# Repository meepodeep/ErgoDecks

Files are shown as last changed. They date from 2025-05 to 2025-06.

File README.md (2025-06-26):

# ErgoDecks not ErgoDOX
- ## Featuring
  - ### Two independent Bluetooth halves.
  - ### 3d printed case
  - ### Custom PCB
  - ### Kalih Choc switch compatibility.

**BOM**

| Item |Quantity |Total price+Shipping|Use in project|Item source|
| --- | --- | --- | --- | --- |
| Pcb  | 5x (minimum order) |$32.05|Mount Everything to this| JLCPCB |
| NRF52840	  | 2x |$10.77|Drive the boards|[Aliexpress](https://www.aliexpress.us/item/3256807018711621.html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)|
|Kalih Choc 10pc	|4x|$31.00|Be switches|[Little Keyboards](https://www.littlekeyboards.com/collections/keyboard-switches/products/kailh-choc-low-profile-switches)|
|Filament of your choice|an amount|0$|make the case|wherever you buy filament ( I have this)|
|301230 lithium battery|2x|$8.76|Power The boards|[Aliexpress](https://www.aliexpress.us/item/3256806602655947.html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)|
|1N4148 Diodes 100pc|1x|$9.26|be diodes|[Aliexpress](https://www.aliexpress.us/item/3256806058794623.html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)|
|Keycaps 1u 10pc|x4|$21.11|be keycaps|[adafruit](https://www.adafruit.com/product/5737)|
|Keycaps 1.5u 2pc|x2|$4.66|be keycaps|[Aliexpress](https://www.aliexpress.us/item/3256805730011012.html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)|
|Everything||$105.62|||

## **Download Gerbers.zip for the gerbers and ErgoDecksVx.3mf/.step/.f3z for the case!**
- ## **Assembly**
  - Solder diodes onto the PCB.
  - Solder switches onto the PCB.
  - Solder microcontrollers onto the pcb.
  - Solder the battery to the bat terminals on the mcu.
  - Attach the battery using double sided tape to the bottom half of the case in the battery area.
  - 
  - Use m3 bolts to secure the pcb and top case to the bottom half of the case.

- ## **Software**
  - download the firmware.zip file and flash the left file to the left half and the right file to the right half by dragging and dropping it into the virtual disk on the MCUs in bootloader mode.






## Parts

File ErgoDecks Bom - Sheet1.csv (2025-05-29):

Item | Quantity | Total price+Shipping | Use In project | Item Source
Pcb | 5x minimum | $32.05 | Mount everything | JLCPCB
NRF52840 | 2x | $10.77 | Drive the boards | https://www.aliexpress.us/item/3256807018711621.html?
Kalih Choc 10pc | 4x | $31.00 | Be switches | https://www.littlekeyboards.com/collections/keyboard-switches/products/kailh-choc-low-profile-switches
301230 lithium battery | 2x | $8.76 | Power the boards | https://www.aliexpress.us/item/3256806602655947
Filament | 1x | $0 | Case | Already owned
1N4148 Diodes 50pc | 1x | $1.28 | be diodes | https://www.aliexpress.us/item/3256806058794623.html
Keycaps 10pc 1u | 3x | $17.10 | Be keycaps | https://www.adafruit.com/product/5737
Keycaps 2pc 1.5u | 2x | $4.66 | be keycaps | https://www.aliexpress.us/item/3256805730011012.htm
Everything |  | $105.62

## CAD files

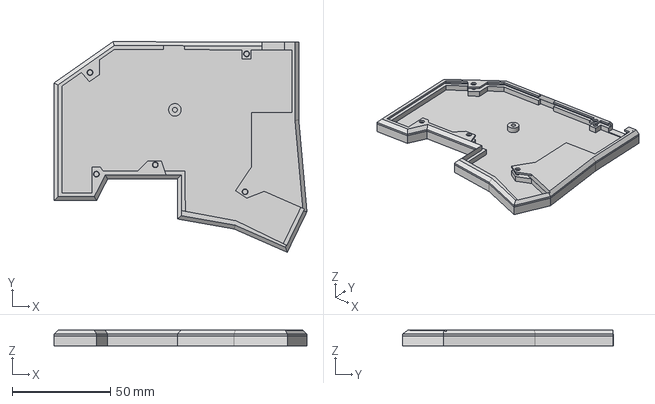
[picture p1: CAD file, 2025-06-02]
ErgoDecks v7.step
128.9 x 107.4 x 8.00 mm

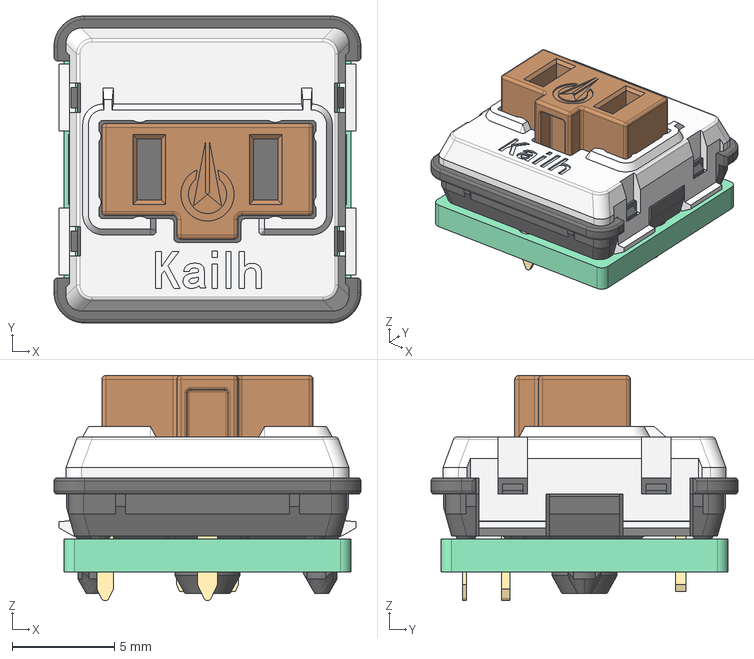
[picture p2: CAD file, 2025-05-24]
ErgoDecks/Kailh Choc Low Profile Switch.step
15.0 x 15.0 x 11.0 mm

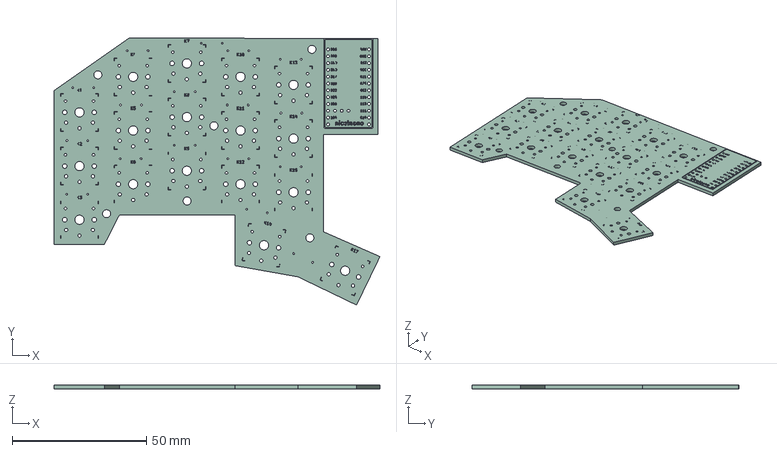
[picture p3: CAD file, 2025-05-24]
ErgoDecks/ErgoDecks.step
121.5 x 99.5 x 1.66 mm
ErgoDecks_silkscreen
ErgoDecks_PCB

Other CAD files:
ErgoDecks v6.f3z

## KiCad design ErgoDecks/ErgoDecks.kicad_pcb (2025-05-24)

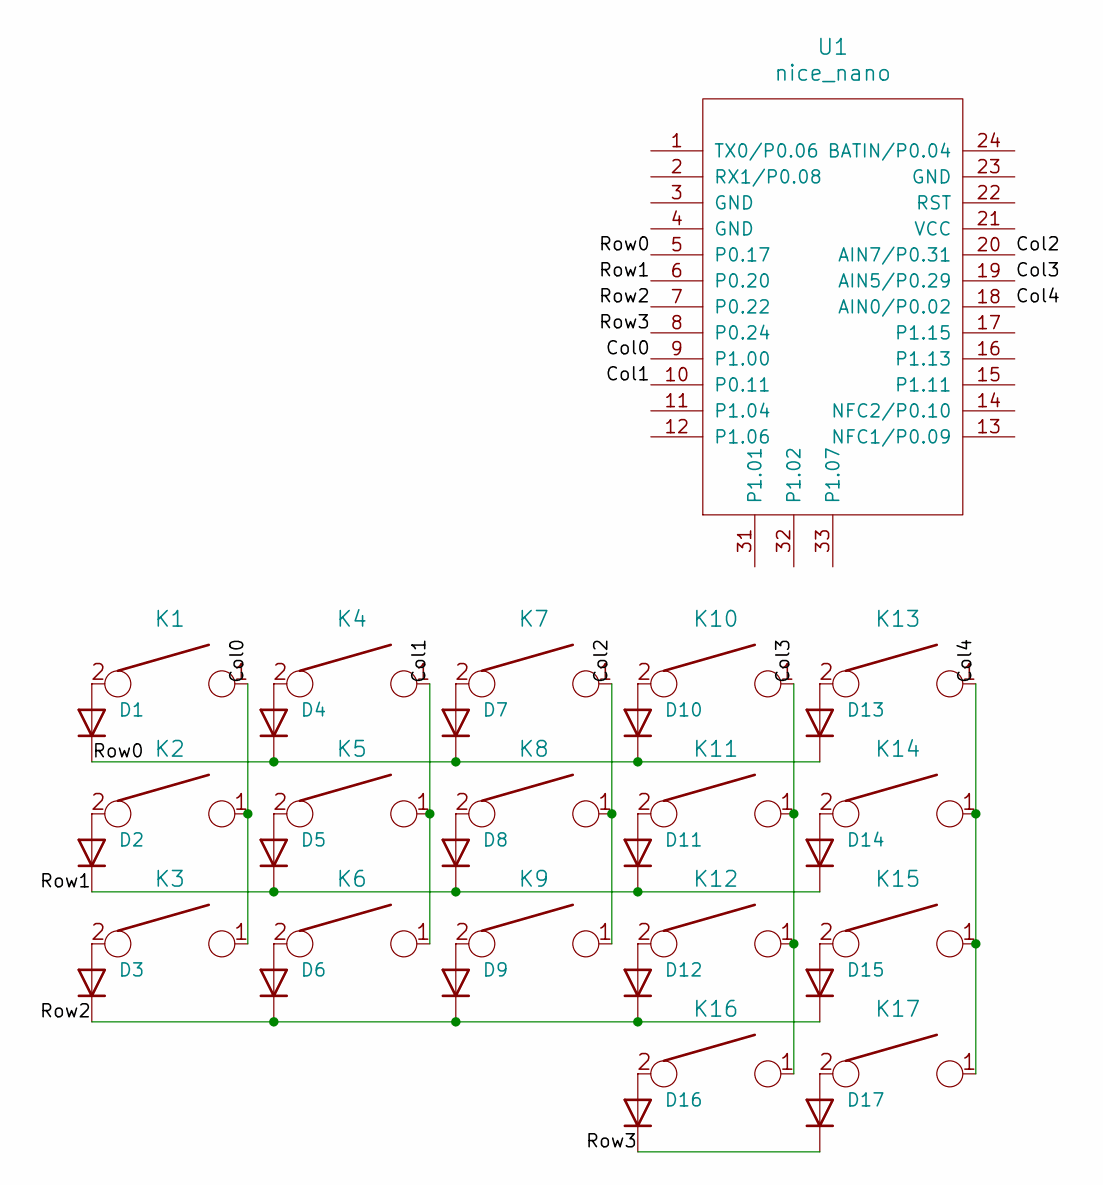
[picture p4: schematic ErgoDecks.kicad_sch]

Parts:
D1, D2, D3, D4, D5, D6, D7, D8, D9, D10, D11, D12, D13, D14, D15, D16, D17: D_SOD123_axial
K1, K2, K3, K4, K5, K6, K7, K8, K9, K10, K11, K12, K13, K14, K15, K16, K17: KEYSW; SW_PG1350_reversible
U1: nice_nano

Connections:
/Col0: K1.1, K2.1, K3.1, U1.9 (P1.00)
/Col1: K4.1, K5.1, K6.1, U1.10 (P0.11)
/Col2: K7.1, K8.1, K9.1, U1.20 (AIN7/P0.31)
/Col3: K10.1, K11.1, K12.1, K16.1, U1.19 (AIN5/P0.29)
/Col4: K13.1, K14.1, K15.1, K17.1, U1.18 (AIN0/P0.02)
/Row0: D1.1 (K), D4.1 (K), D7.1 (K), D10.1 (K), D13.1 (K), U1.5 (P0.17)
/Row1: D2.1 (K), D5.1 (K), D8.1 (K), D11.1 (K), D14.1 (K), U1.6 (P0.20)
/Row2: D3.1 (K), D6.1 (K), D9.1 (K), D12.1 (K), D15.1 (K), U1.7 (P0.22)
/Row3: D16.1 (K), D17.1 (K), U1.8 (P0.24)
unnamed: D1.2 (A), K1.2
unnamed: D2.2 (A), K2.2
unnamed: D3.2 (A), K3.2
unnamed: D4.2 (A), K4.2
unnamed: D5.2 (A), K5.2
unnamed: D6.2 (A), K6.2
unnamed: D7.2 (A), K7.2
unnamed: D8.2 (A), K8.2
unnamed: D9.2 (A), K9.2
unnamed: D10.2 (A), K10.2
unnamed: D11.2 (A), K11.2
unnamed: D12.2 (A), K12.2
unnamed: D13.2 (A), K13.2
unnamed: D14.2 (A), K14.2
unnamed: D15.2 (A), K15.2
unnamed: D16.2 (A), K16.2
unnamed: D17.2 (A), K17.2

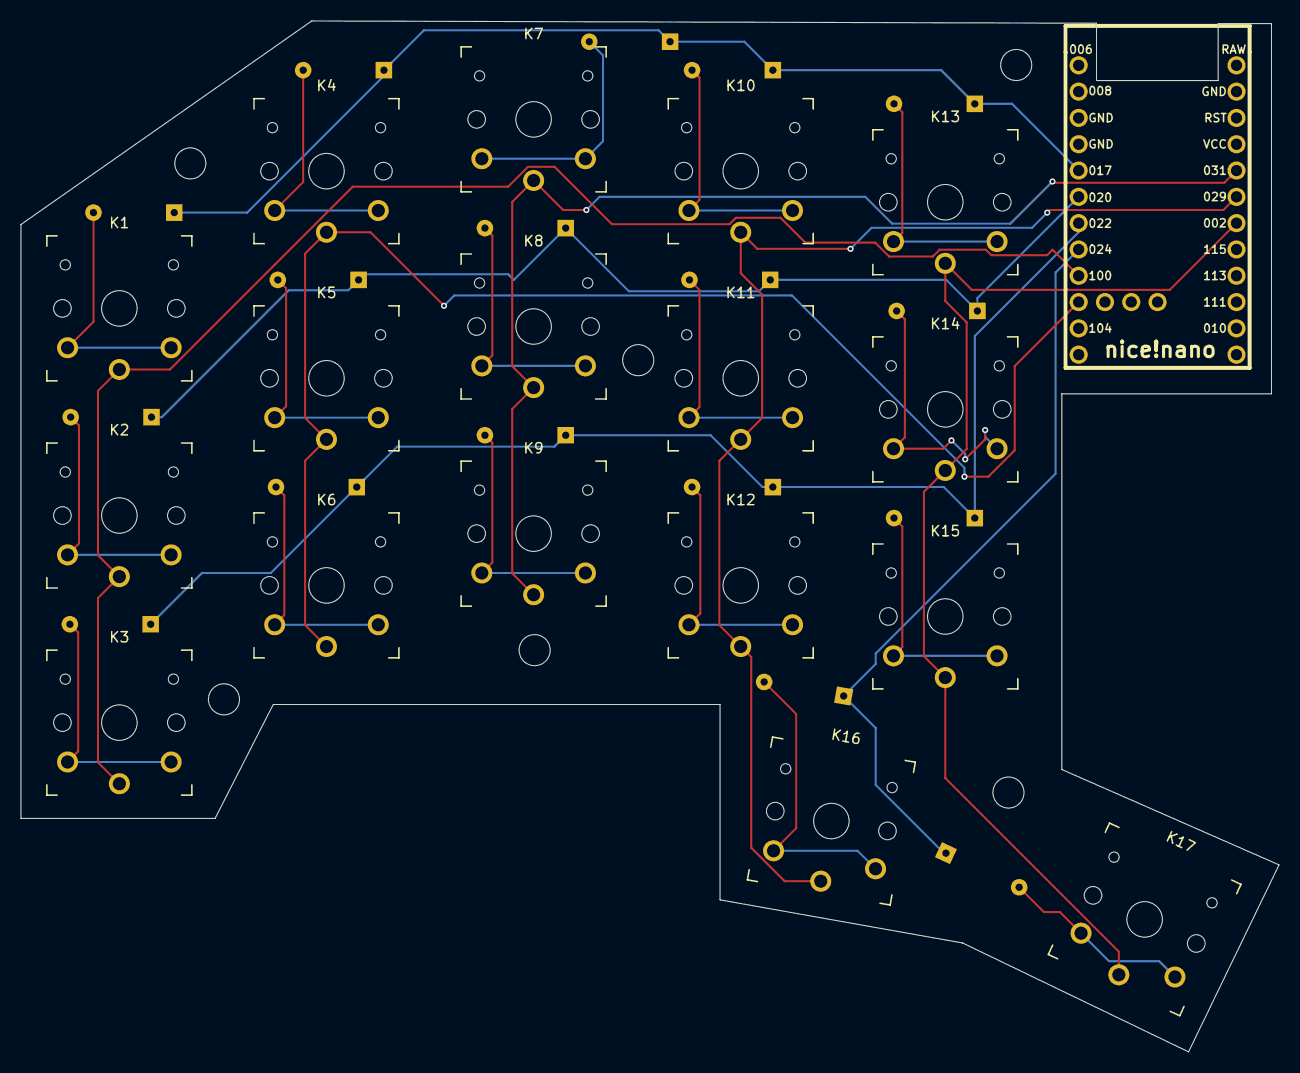
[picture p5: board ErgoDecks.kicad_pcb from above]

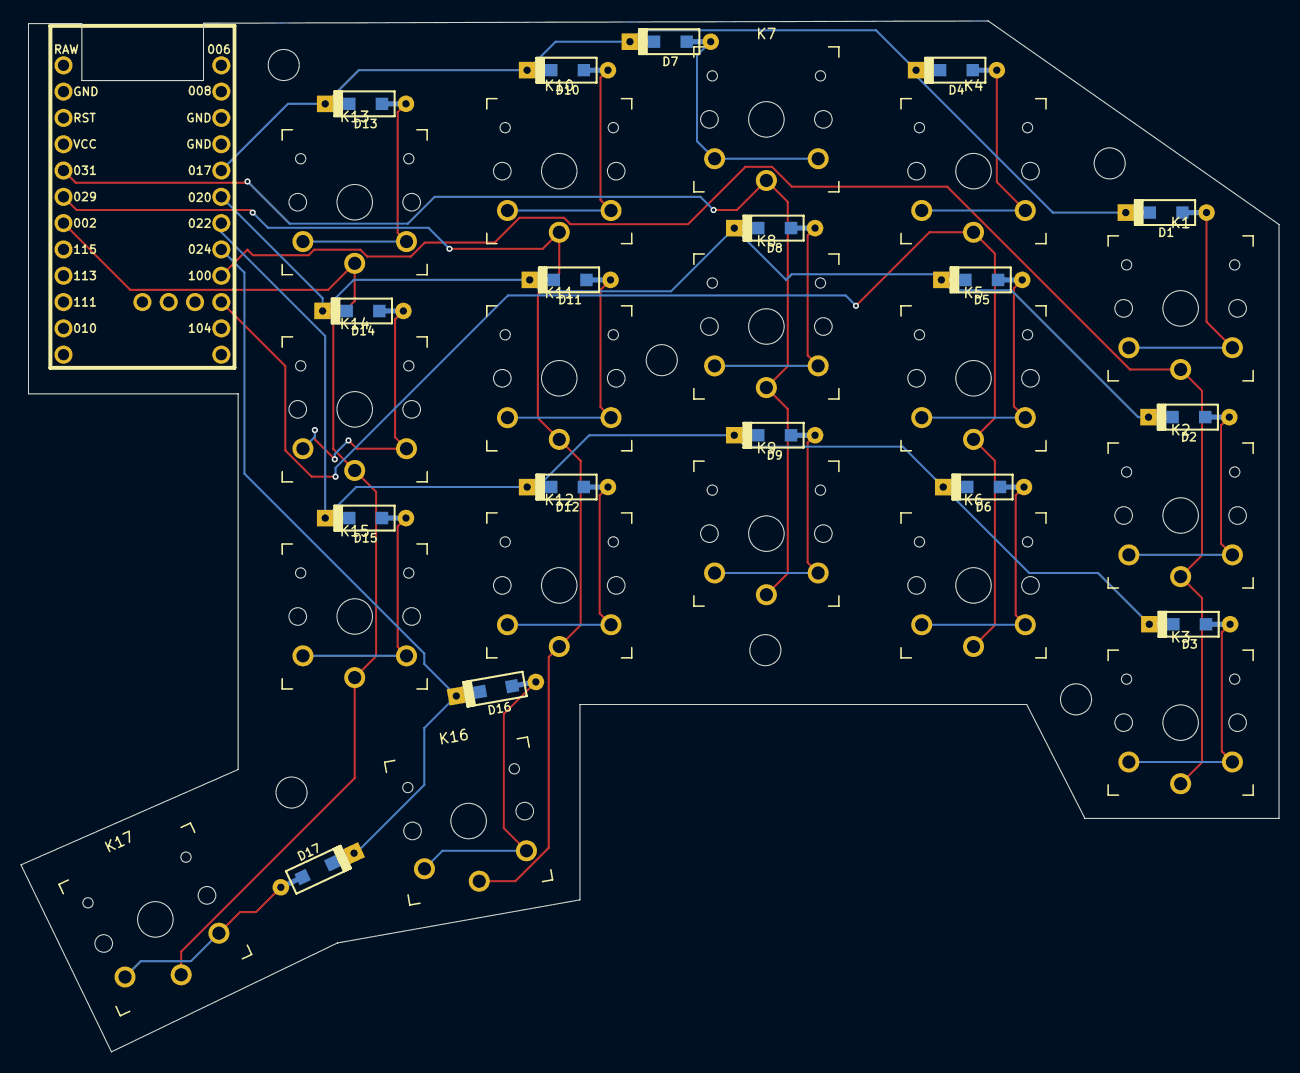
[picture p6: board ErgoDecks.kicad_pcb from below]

Board: 2 copper layers, 121.5 x 99.5 mm, 35 parts (17 on the bottom side), 26 nets.

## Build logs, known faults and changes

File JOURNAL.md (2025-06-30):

---
title: "ErgoDecks"
author: "meepodeep"
description: "split ergo keyboard with 2 independent wireless halves"
created_at: "2025-05-23"
Total time: "35 Hours"
---
# 5/23/25 made the PCB!

Today, I designed the PCB for the ErgoDecks, I also researched what components to use. I decided on the nice!nano for the MCU based on a recommendation/inspiration from another Hack Clubber!




**Total time spent: 3h**

# 5/24/25 Made the case and updated PCB!

Today, I designed the Case in fusion and updated the PCB to support choc instead of mx switches.




**Total time spent: 6h**

# 5/28/25 Got rejected and made some changes!

Today I realized I needed to change up my bom a bit. I changed the mcu to a generic one and I also made some updates to the case.

**Total time spent: 1h**

# 6/23/25  So close but so far away.

Today I got all of my parts and I started assembling the keyboards. I soldered on all of the switches, diodes, and the MCU, but what I didn't realize is I soldered the MCU one set of pins offset up. And when I desoldered it from the pins, neither of them connected to my pc anymore.

**Total time spent: 11h**

# 6/25/25 a ITWORKS! but i suck at typing on it.....

Today I finally got it working! I wrote my own config for zmk and replaced the dead mcus! i still suck at typing thoooo i think thats just skill issue not keyboard issue.....





**Total time spent: 12h**

# 6/29/2025 I did the poster!

Today I made the poster!
ErgoDecks
**Total time spent 2h**
